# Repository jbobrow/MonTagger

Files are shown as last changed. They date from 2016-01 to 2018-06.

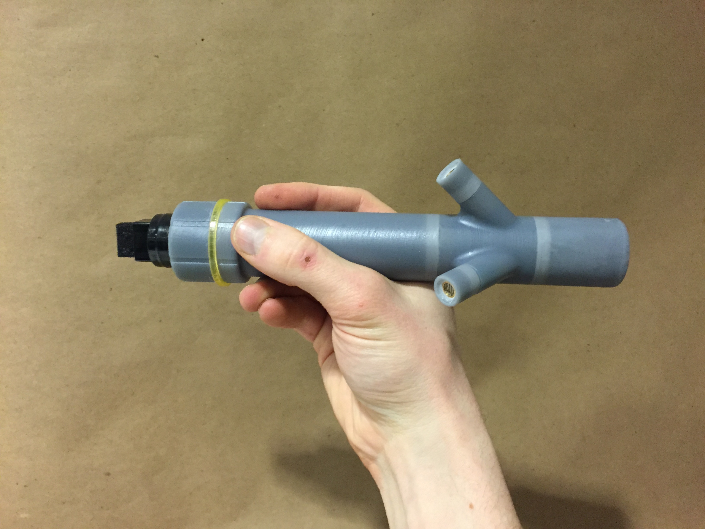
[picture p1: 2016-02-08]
Documentation/Images/montagger_lasers_off.jpg

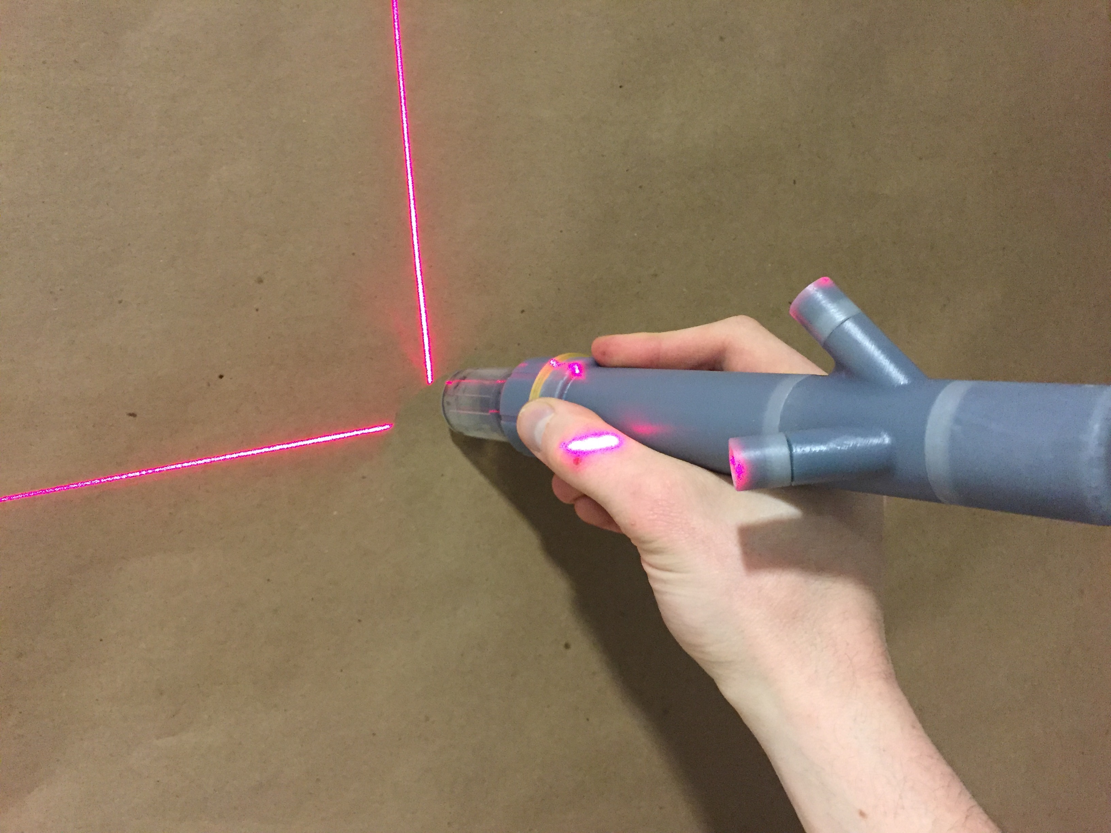
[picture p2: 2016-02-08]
Documentation/Images/montagger_lasers_on.jpg

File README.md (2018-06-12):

# MonTagger 
## Graffiti Field Recorder

If the idea of a graffiti recording device is new or foreign to you, take a look [here](http://graffitimarkuplanguage.com) at some wonderful work that has preceded this project. In short, the idea is at least two-fold. One aim is to provide artists with archival material and another is to extend the art of graffiti and give artists access to their performance through data. As the past few years have seen major destruction of large scale graffiti art (5Pointz, MTA), it was on my mind that giving artists a tool to record their work could be both historically important as well as creatively empowering. Additionally, in the past year, collaborations with [Shantell Martin](http://www.shantellmartin.com/), had us discussing different ways to engage with her drawing process and what she could do if she had the kind of information embedded in her performance of the artwork itself.

## Prior work

Before I introduce my design and how you can create it for yourself, I want to note the prior work and design decisions for my recording device. The most notable of tools designed for graffiti artists is [µTagger](http://thefactoryfactory.com/mtagger/), by [Joshua Noble](http://thefactoryfactory.com/) in 2011, which combines a clever hack of an optic flow sensor from a computer mouse and a 6-dof IMU for sensing orientation. My main critique of the project is that while it satisfies many of the needs for a graffiti recording field device, it seems non-trivial to recreate. Even though these electronics are only reducing in price and increasing in accessibility, I wanted to look for a low-tech solution that relies more heavily on tools we already carry, and make the device as minimal as possible.

## MonTagger

Named for the protagonist of Fahrenheit 451 and French for "my tagger," MonTagger along with an OpenFrameworks Application provide a means for tracking a pen or can through CV(computer vision). To solve the problem of occlusion to the camera, the device emits 2 laser lines which intersect at the point of contact for a pen or spray can. This means that the camera simply needs to see 2 line segments to then compute where they intersect, resulting in where the pen or can is actively being used. The device only requires:

1. 2x lasers ([red](http://www.amazon.com/Farhop-650nm-Laser-9X21mm-Module/dp/B0195SNRAC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 "Red Lasers"), green, IR...)
2. [3x AAA batteries](http://www.amazon.com/Panasonic-BK-4MCCA4BA-Pre-Charged-Rechargeable-Batteries/dp/B00JHKSMJK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) (each provides 1.2volts x3 = 3.6volts)
3. [Battery Holder](http://www.amazon.com/uxcell®-Battery-Holder-Batteries-Flashlight/dp/B00GYWOG30/ref=sr_1_3?ie=UTF8&qid=1454649125&sr=8-3&keywords=AAA+battery+holder) (or similar on amazon)
4. [Push button](http://www.amazon.com/microtivity-IM206-6x6x6mm-Tact-Switch/dp/B004RXKWI6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) (switch)
5. 3D printed case to attach the above to writing instrument
(Note: I would love to see a hack for laser cut parts instead, it is so much faster and accessible to recreate)

I will outline the design as well as the steps for recreation (even though that is largely just printing the 3D files and compiling this OpenFrameworks app). The intention is not to suggest that this is a perfect solution, but I hadn't ever seen anything done this way, and thought taking advantage of some simply math would be a fun way to solve this problem. I will also outline some limitations and possible solutions.

3D files are both included here and on Thingiverse: http://www.thingiverse.com/thing:1318763

## How it works

Before we start building, let's take a quick stroll down how the heck this thing is going to work. It takes everyone a moment or two to visualize what is going to happen and how it is going to work, but with some visual aids, I have a feeling this will make sense quite quickly.

## Intersecting Lines

Finding the point where two lines intersect is easy, in fact the math looks like this:

```
    // Adapted from the nice function seen here :)
    // http://flassari.is/2008/11/line-line-intersection-in-cplusplus/
    
    // Store the values for fast access and easy
    // equations-to-code conversion
    float x1 = line1Start.x;
    float x2 = line1End.x;
    float x3 = line2Start.x;
    float x4 = line2End.x;
    
    float y1 = line1Start.y;
    float y2 = line1End.y;
    float y3 = line2Start.y;
    float y4 = line2End.y;
    
    float d = (x1 - x2) * (y3 - y4) - (y1 - y2) * (x3 - x4);
    // If d is zero, there is no intersection
    if (d == 0) return;
    
    // Get the x and y
    float pre = (x1*y2 - y1*x2);
    float post = (x3*y4 - y3*x4);
    float x = ( pre * (x3 - x4) - (x1 - x2) * post ) / d;
    float y = ( pre * (y3 - y4) - (y1 - y2) * post ) / d;
```
We don't need to see where the two lines meet to know where they meet. With our naked eye this is true, but the computer can also remember and record where those points are, which allow it to recreate the path of the intersection of the two lines. It is important to note that only some part of each line needs to be visible, and if multiple parts of the same line are seen, that is okay too!

## Creating Laser Lines

To use lines, we are going to make some bright visible laser lines, or at least visible to a camera. Depending on whether you use IR Lasers for discrete tag tracking or Red/Green lasers, line generators are the same. The laser which is focussed to a single point (Note: a single point is defined as a tightly clustered circle... no need to get too technical about this, a laser makes a dot), is going to pass through what is called a Line Generator. The line generator is basically a bunch of glass cylinders, or half cylinders... and they diffract the laser into a single line at the angle specified by the generator. I chose to use ~90º generators, but slightly smaller would be fine too. In fact, might even be better since 90º has the laser hitting your hand and trailing off to infinity, which could hurt someones eye.

## Orientation of Laser Lines

Placing the lasers rotationally 90º apart, so as to create one quadrant of an XY plane gives us a bit more knowledge than simply where the lines intersect. Rotating the pen or can 360º results in unique positions of the lines all the way around, so we can sense the rotation of drawing, easily. The easiest way to do this is to find the line between the two laser lines, or equidistant from them at every point. This line will be our reference for what angle we are holding our drawing device at.

## Tilt Sensing

You might be wondering if there is anything else we can sense by seeing these laser lines. We get X,Y coordinates from their intersection, we get Ø from the line between the lines, and we can also get some information about the tilt of the pen... occasionally. By measuring the angle between the two found lines, we can determine a tilt along that axis. To be accurate about tilt, we could try and used dashed line lasers or a third laser to act as a tilt reference, but in short, I thought it kind of need that we can get at least some information about this, and if the artist so chooses, she can decide to draw with the pen in a specific orientation to maximize tilt information.

## License

Copyright (c) 2015 Jonathan Bobrow

Permission is hereby granted, free of charge, to any person obtaining a copy of this software and associated documentation files (the "Software"), to deal in the Software without restriction, including without limitation the rights to use, copy, modify, merge, publish, distribute, sublicense, and/or sell copies of the Software, and to permit persons to whom the Software is furnished to do so, subject to the following conditions:

The above copyright notice and this permission notice shall be included in all copies or substantial portions of the Software.

THE SOFTWARE IS PROVIDED "AS IS", WITHOUT WARRANTY OF ANY KIND, EXPRESS OR IMPLIED, INCLUDING BUT NOT LIMITED TO THE WARRANTIES OF MERCHANTABILITY, FITNESS FOR A PARTICULAR PURPOSE AND NONINFRINGEMENT. IN NO EVENT SHALL THE AUTHORS OR COPYRIGHT HOLDERS BE LIABLE FOR ANY CLAIM, DAMAGES OR OTHER LIABILITY, WHETHER IN AN ACTION OF CONTRACT, TORT OR OTHERWISE, ARISING FROM, OUT OF OR IN CONNECTION WITH THE SOFTWARE OR THE USE OR OTHER DEALINGS IN THE SOFTWARE.
Status API Training Shop Blog About Pricing
© 2016 GitHub, Inc. Terms Privacy Security Contact Help

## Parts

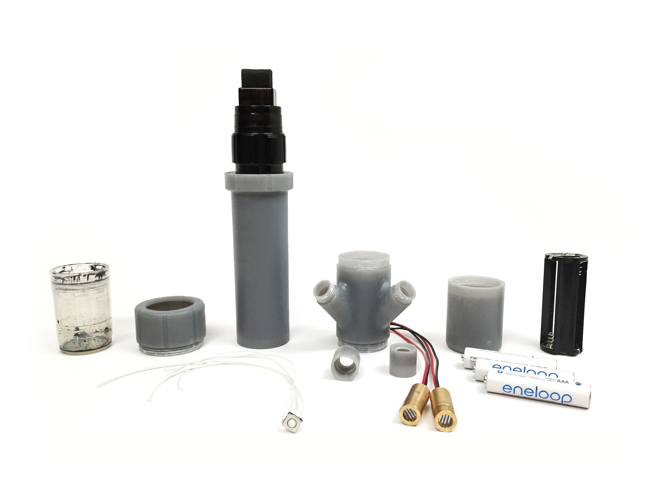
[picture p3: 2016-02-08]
Documentation/Images/montagger_parts_all.jpg

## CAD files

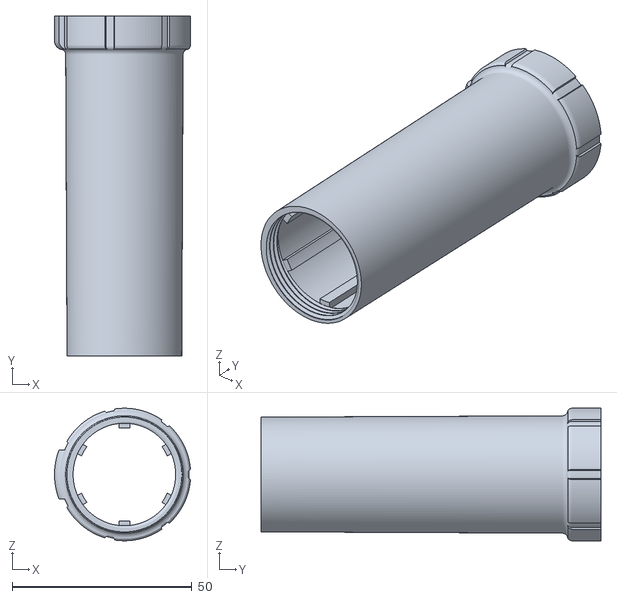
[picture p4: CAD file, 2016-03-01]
Hardware/01_Montagger_Pen_Barrel_alt.stl
37.8 x 94.6 x 36.9

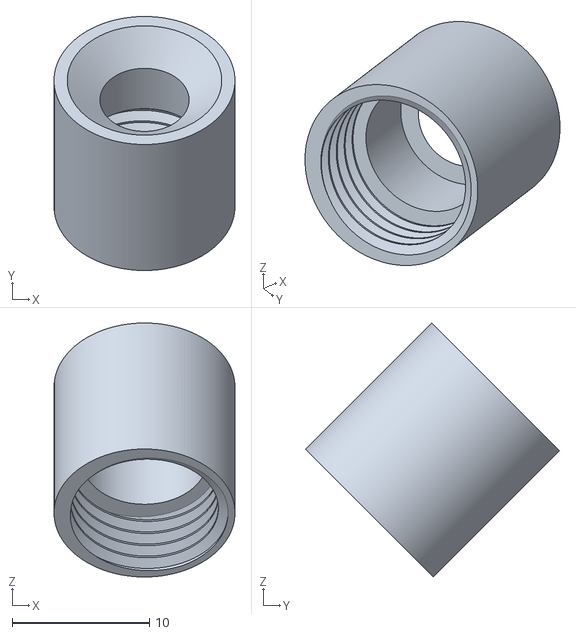
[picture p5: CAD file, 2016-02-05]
Hardware/04_Montagger_Laser_Cap.stl
13.2 x 18.5 x 18.5

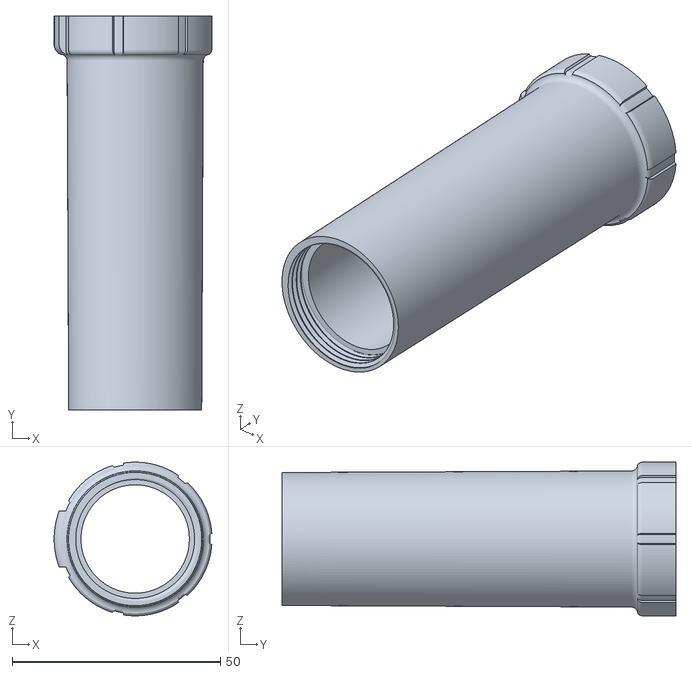
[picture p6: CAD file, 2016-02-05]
Hardware/01_Montagger_Pen_Barrel.stl
37.8 x 94.6 x 36.9

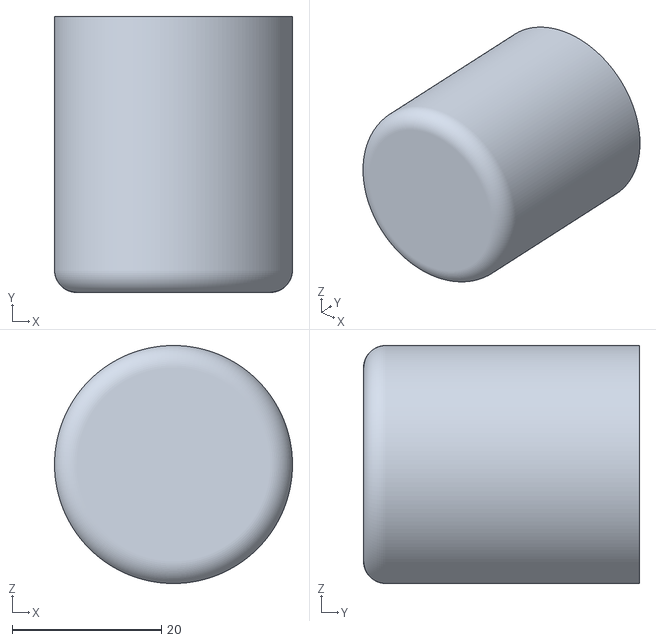
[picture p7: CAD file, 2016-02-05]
Hardware/05_Montagger_Battery_Cap.stl
31.9 x 37.0 x 31.9

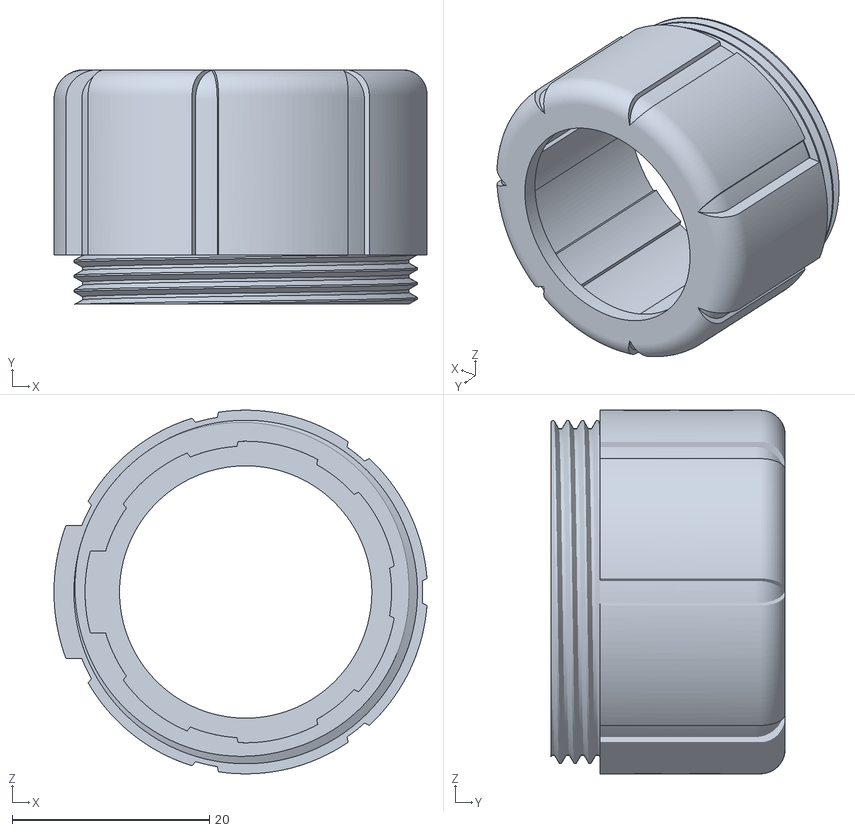
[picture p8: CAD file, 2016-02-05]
Hardware/02_Montagger_Pen_Cap.stl
37.8 x 23.8 x 36.9

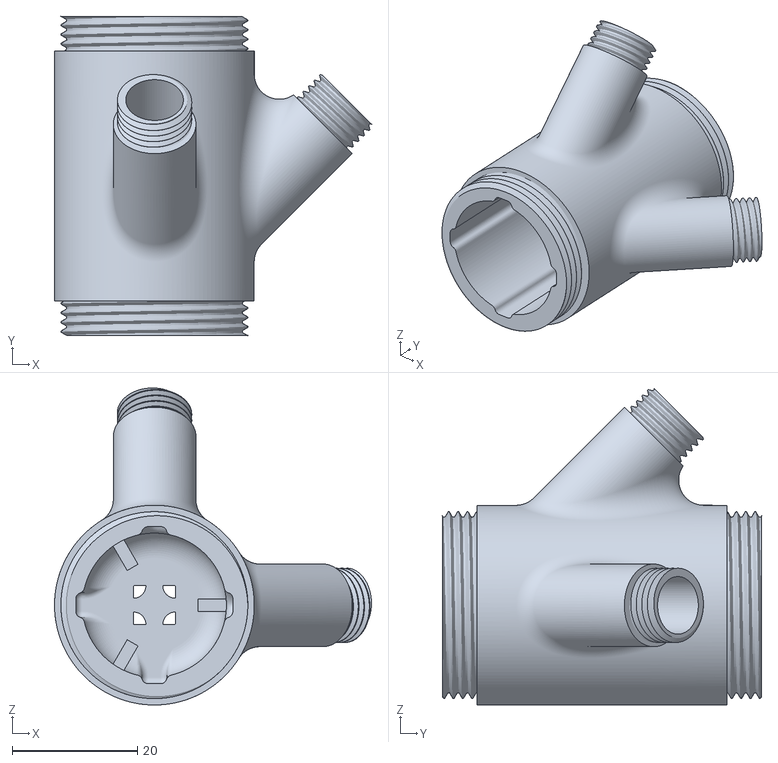
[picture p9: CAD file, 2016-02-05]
Hardware/03_Montagger_Laser_Body.stl
50.6 x 51.0 x 50.6

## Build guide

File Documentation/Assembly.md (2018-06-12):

# MonTagger Assembly

## Parts

#### 3D Printed
1. Pen Cap
2. Pen Body
3. Laser Body
4. Laser Cap (x2)
5. Battery Cap

#### Purchased or Found
1. Lasers (x2)
2. AAA Batteries (x3)
3. Battery Holder
4. Button
5. Wires

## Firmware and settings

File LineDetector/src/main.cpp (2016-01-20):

#include "ofMain.h"
#include "ofApp.h"

//========================================================================
int main( ){
	ofSetupOpenGL(700,800,OF_WINDOW);			// <-------- setup the GL context

	// this kicks off the running of my app
	// can be OF_WINDOW or OF_FULLSCREEN
	// pass in width and height too:
	ofRunApp(new ofApp());

}

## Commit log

2016-01-20 adding line detector with red channel filter
2016-02-01 adding iOS app for OF 0.9, working with basic line detection and some on screen controls for switching video mode and showing lines drawn
2016-02-05 adding readme and 3D files
    [01_Montagger_Pen_Barrel.stl, 02_Montagger_Pen_Cap.stl, 03_Montagger_Laser_Body.stl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]
2016-02-08 move 3d files to hardware folder and add documentation images
    [01_Montagger_Pen_Barrel.stl, 02_Montagger_Pen_Cap.stl, 03_Montagger_Laser_Body.stl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]
2016-02-08 starting assembly documentation markdown file
2016-03-01 adding a pen barrel that uses less material for a FormLabs print. Also including a layout of all of the pieces to print in a single go on the Form2
    [01_Montagger_Pen_Barrel_alt.stl]
2018-06-12 Update Assembly.md
    formatting
